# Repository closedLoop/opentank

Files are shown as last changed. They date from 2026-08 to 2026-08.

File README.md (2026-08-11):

# opentank
(WORK IN PROGRESS) A smart home sensor hub with ESP32-C6, rich analog capabilities, and full self-powering.
https://youtu.be/-s6jZ4U3TzU

## Important note!!!
The D-/D+ lines at the Type-C connector and SDA/SCL lines for U17 are still swapped!!! If you want to modify this and make changes for your own project, keep this in mind! Otherwise feel free to have a peak around in the PCB layout. Another thing: the templateforconfiguration.yaml (for Home Assistant) is still somewhat broken because the value will never go below 0 with this logic. I'll need to fix this soon. fulldevicecode.yaml is what the PCB gets programmed with, and works flawlessly as far as I've observed (2 months+ runtime so far). I also will be cleaning this up soon though by trying to make some contributions to ESPHome's repo to get rid of the need for so many lambdas. Questions? Email me at rain@haaseindustries.com or comment on my YouTube video.

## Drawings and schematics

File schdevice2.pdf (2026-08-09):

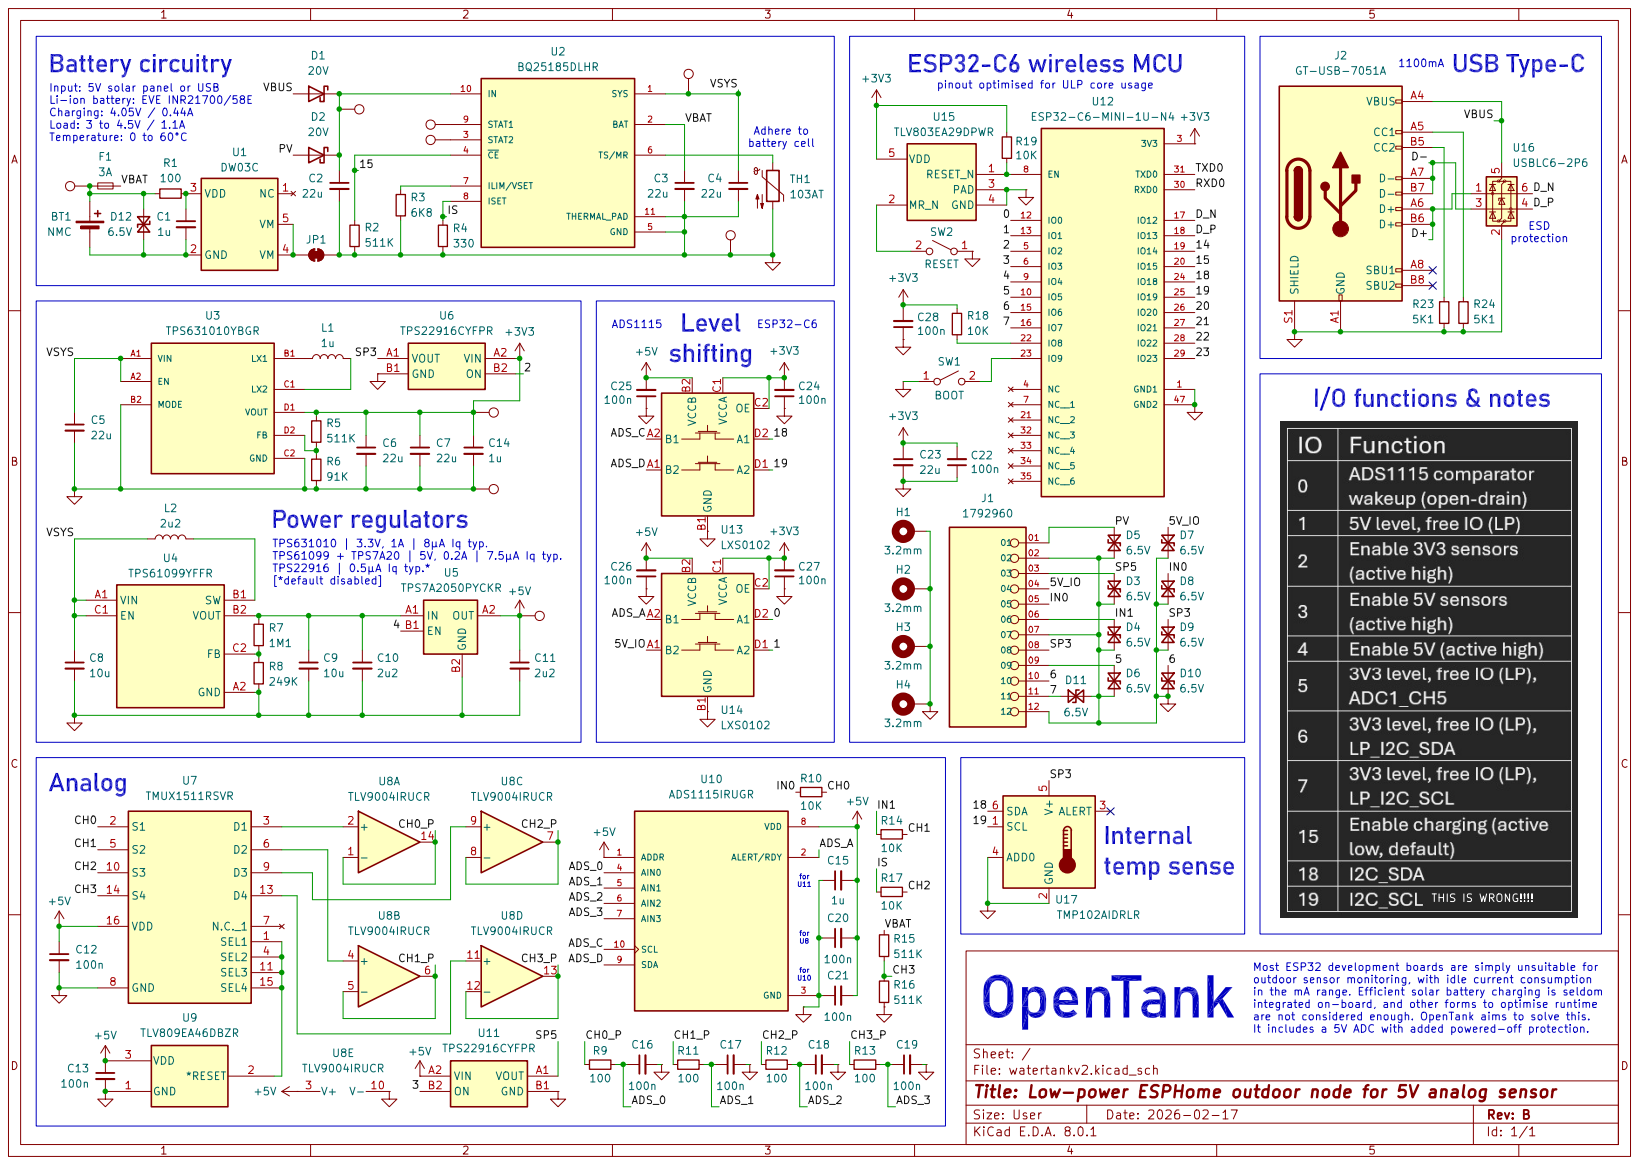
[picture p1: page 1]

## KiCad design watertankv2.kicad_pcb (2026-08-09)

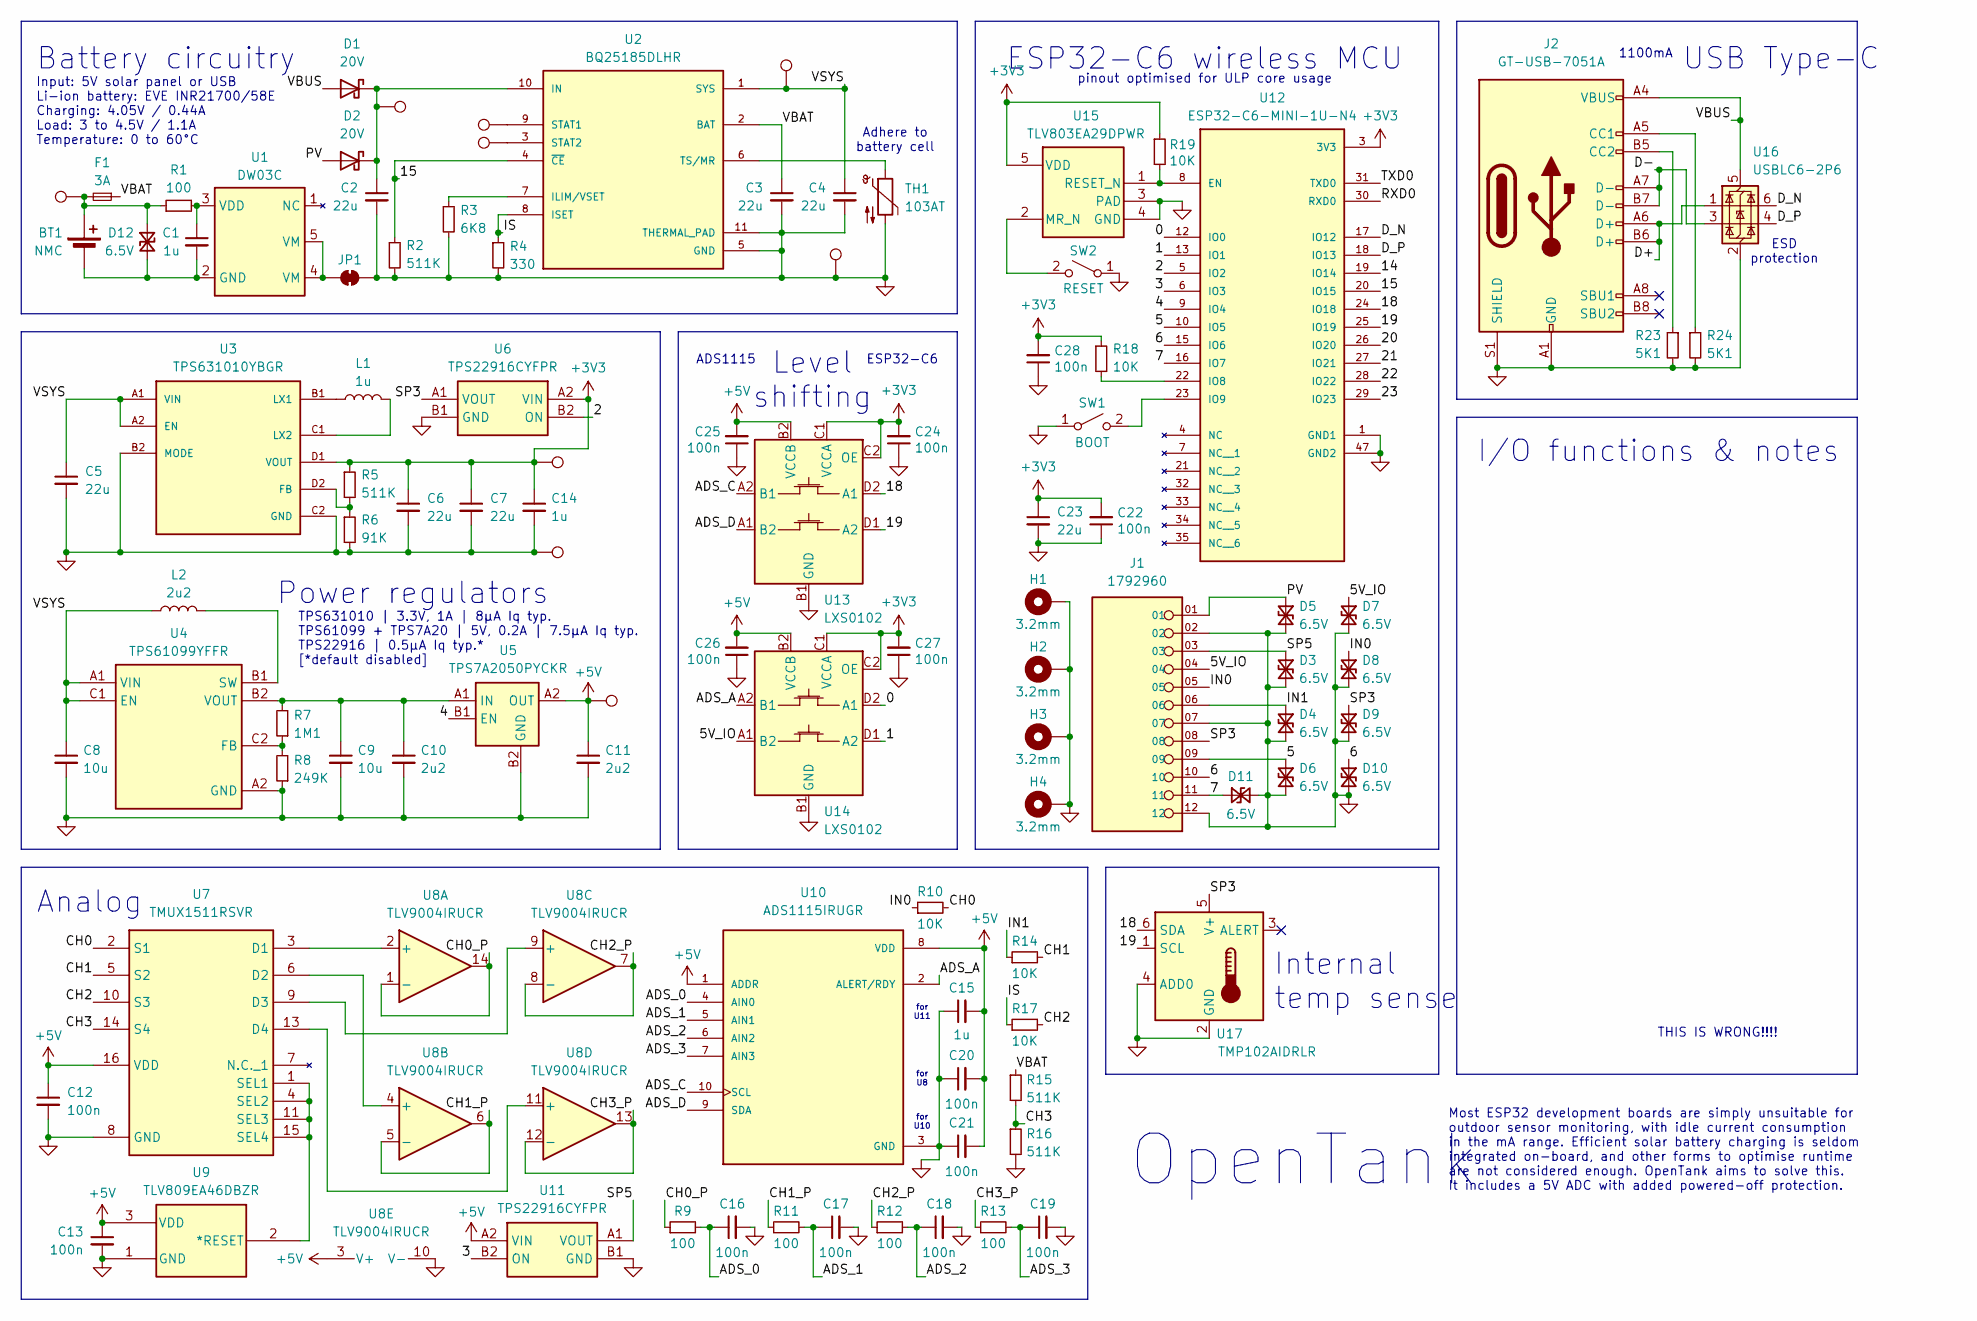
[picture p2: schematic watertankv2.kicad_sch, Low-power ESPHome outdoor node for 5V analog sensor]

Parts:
BT1: NMC; 21700holder
C1, C14, C15: 1u; C_0402_1005Metric; MPN GRM155Z71A105KE01D
C2, C3, C4, C5, C6, C7, C23: 22u; C_0805_2012Metric; MPN GRM21BR61A226ME44L
C8, C9: 10u; C_1206_3216Metric; MPN GRM31CR71C106KAC7L
C10, C11: 2u2; C_0402_1005Metric; MPN GRM155Z71A225KE44D
C12, C13, C16, C17, C18, C19, C20, C21, C22, C24, C25, C26, C27, C28: 100n; C_0201_0603Metric; MPN GRM033R61A104KE15D
D1, D2: 20V; D_SOD-123; MPN SM5817PL-TP
D3, D4, D5, D6, D7, D8, D9, D10, D11, D12: 6.5V; D_SOD-923; MPN DF2S8.2FS,L3M
F1: 3A; Fuse_1206_3216Metric; MPN C1F 3
H1, H2, H3, H4: 3.2mm; MountingHole_3.2mm_M3_DIN965_Pad
J1: 1792960; PHOENIX_1792960; MPN 1792960
J2: GT-USB-7051A; USB_C_Receptacle_G-Switch_GT-USB-7051x; MPN GT-USB-7051A
JP1: I_SNSEXT; SolderJumper-2_P1.3mm_Bridged2Bar_Pad1.0x1.5mm
L1: 1u; 74404043010A; MPN 74404043010A
L2: 2u2; L_1008_2520Metric; MPN LQM2HPN2R2MG0L
R1, R9, R11, R12, R13: 100; R_0201_0603Metric; MPN RC0201JR-07100RL
R2, R5, R15, R16: 511K; R_0201_0603Metric; MPN RC0201FR-07511KL
R3: 6K8; R_0402_1005Metric; MPN RC0402FR-076K8L
R4: 330; R_0402_1005Metric; MPN RC0402FR-07330RL
R6: 91K; R_0201_0603Metric; MPN RC0201FR-0791KL
R7: 1M1; R_0201_0603Metric; MPN RC0201FR-071M1L
R8: 249K; R_0201_0603Metric; MPN RC0201FR-07249KL
R10, R14, R17, R18, R19: 10K; R_0201_0603Metric; MPN RC0201FR-0710KL
R23, R24: 5K1; R_0402_1005Metric; MPN RC0402FR-075K1L
SW1: BOOT; SW_SPST_B3U-1000P; MPN HX-B3U-1000P-1.6N
SW2: RESET; SW_SPST_B3U-1000P; MPN HX-B3U-1000P-1.6N
TH1: 103AT; SolderWire-0.1sqmm_1x02_P3.6mm_D0.4mm_OD1mm; MPN 103AT-4-70374
TP1: BQ_IN; TestPoint_Pad_D2.0mm
TP2: STAT1; TestPoint_Pad_D2.0mm
TP3: STAT2; TestPoint_Pad_D2.0mm
TP4: 3V3; TestPoint_Pad_D2.0mm
TP5, TP9: GND; TestPoint_Pad_D2.0mm
TP6: 5V; TestPoint_Pad_D2.0mm
TP7: SYS; TestPoint_Pad_D2.0mm
TP10: VBATSNS; TestPoint_Pad_D2.0mm
U1: DW03C; SOT-23-5; MPN DW03C
U2: BQ25185DLHR; IC_BQ25185DLHR; MPN BQ25185DLHR
U3: TPS631010YBGR; IC_TPS631010YBGR; MPN TPS631010YBGR
U4: TPS61099YFFR; BGA6C40P2X3_88X123X62; MPN TPS61099YFFR
U5: TPS7A2050PYCKR; BGA4C35P2X2_62X62X33; MPN TPS7A2050PYCKR
U6, U11: TPS22916CYFPR; BGA4C40P2X2_75X75X50; MPN TPS22916CYFPR
U7: TMUX1511RSVR; QFN40P180X260X55-16N; MPN TMUX1511RSVR
U8: TLV9004IRUCR; Texas_S-PX2QFN-14; MPN TLV9004IRUCR
U9: TLV809EA46DBZR; SOT-23; MPN TLV809EA46DBZR
U10: ADS1115IRUGR; IC_ADS1115IRUGR; MPN ADS1115IRUGR
U12: ESP32-C6-MINI-1U-N4; XCVR_ESP32-C6-MINI-1U-N4; MPN ESP32-C6-MINI-1U-N4
U13, U14: LXS0102; Texas_DSBGA-8_0.9x1.9mm_Layout2x4_P0.5mm; MPN LXS0102GBAEX
U15: TLV803EA29DPWR; Texas_X2SON-5_0.8x0.8mm_P0.48mm; MPN TLV803EA29DPWR
U16: USBLC6-2P6; SOT-666; MPN USBLC6-2P6
U17: TMP102AIDRLR; SOT-563; MPN TMP102AIDRLR

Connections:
+3V3: C6.1, C7.1, C14.1, C22.2, C23.1, C24.2, C27.2, C28.2, R5.1, R18.1, R19.1, TP4.1, U3.D1 (VOUT), U6.A2 (VIN), U12.3 (3V3), U13.C1 (VCCA), U13.C2 (OE), U14.C1 (VCCA), U14.C2 (OE), U15.5 (VDD)
+5V: C11.1, C12.1, C13.1, C15.2, C20.2, C21.2, C25.2, C26.2, TP6.1, U5.A2 (OUT), U7.16 (VDD), U8.3 (V+), U9.3 (VDD), U10.1 (ADDR), U10.8 (VDD), U11.A2 (VIN), U13.B2 (VCCB), U14.B2 (VCCB)
/0: U12.12 (IO0), U14.D2 (A1)
/1: U12.13 (IO1), U14.D1 (A2)
/2: U6.B2 (ON), U12.5 (IO2)
/3: U11.B2 (ON), U12.6 (IO3)
/4: U5.B1 (EN), U12.9 (IO4)
/5: D6.1 (A1), J1.09, U12.10 (IO5)
/5V_IO: D7.1 (A1), J1.04, U14.A1 (B2)
/6: D10.1 (A1), J1.10, U12.15 (IO6)
/7: D11.1 (A1), J1.11, U12.16 (IO7)
/14: U12.19 (IO14)
/15: R2.1, U2.4 (~CE), U12.20 (IO15)
/18: U12.24 (IO18), U13.D2 (A1), U17.6 (SDA)
/19: U12.25 (IO19), U13.D1 (A2), U17.1 (SCL)
/20: U12.26 (IO20)
/21: U12.27 (IO21)
/22: U12.28 (IO22)
/23: U12.29 (IO23)
/ADS_0: C16.1, R9.2, U10.4 (AIN0)
/ADS_1: C17.1, R11.2, U10.5 (AIN1)
/ADS_2: C18.1, R12.2, U10.6 (AIN2)
/ADS_3: C19.1, R13.2, U10.7 (AIN3)
/ADS_A: U10.2 (ALERT/RDY), U14.A2 (B1)
/ADS_C: U10.10 (SCL), U13.A2 (B1)
/ADS_D: U10.9 (SDA), U13.A1 (B2)
/CH0: R10.2, U7.2 (S1)
/CH0_P: R9.1, U8.1 (-), U8.14
/CH1: R14.2, U7.5 (S2)
/CH1_P: R11.1, U8.5 (-), U8.6
/CH2: R17.2, U7.10 (S3)
/CH2_P: R12.1, U8.7, U8.8 (-)
/CH3: R15.2, R16.1, U7.14 (S4)
/CH3_P: R13.1, U8.12 (-), U8.13
/D+: J2.A6 (D+), J2.B6 (D+), U16.1 (I/O1)
/D-: J2.A7 (D-), J2.B7 (D-), U16.3 (I/O2)
/D_N: U12.17 (IO12), U16.6 (I/O1)
/D_P: U12.18 (IO13), U16.4 (I/O2)
/IN0: D8.1 (A1), J1.05, R10.1
/IN1: D4.1 (A1), J1.06, R14.1
/IS: R4.1, R17.1, U2.8 (ISET)
/PV: D2.2 (A), D5.1 (A1), J1.01
/RXD0: U12.30 (RXD0)
/SP3: D9.1 (A1), J1.08, U6.A1 (VOUT), U17.5 (V+)
/SP5: D3.1 (A1), J1.03, U11.A1 (VOUT)
/TXD0: U12.31 (TXD0)
/VBAT: C3.1, F1.1, R15.1, U2.2 (BAT)
/VBUS: D1.2 (A), J2.A4 (VBUS), J2.A9 (VBUS), J2.B4 (VBUS), J2.B9 (VBUS), U16.5 (VBUS)
/VSYS: C4.1, C5.1, C8.1, L2.1, TP7.1, U2.1 (SYS), U3.A1 (VIN), U3.A2 (EN), U4.A1 (VIN), U4.C1 (EN)
GND: C2.2, C3.2, C4.2, C5.2, C6.2, C7.2, C8.2, C9.2, C10.2, C11.2, C12.2, C13.2, C14.2, C15.1, C16.2, C17.2, C18.2, C19.2, C20.1, C21.1, C22.1, C23.2, C24.1, C25.1, C26.1, C27.1, C28.1, D3.2 (A2), D4.2 (A2), D5.2 (A2), D6.2 (A2), D7.2 (A2), D8.2 (A2), D9.2 (A2), D10.2 (A2), D11.2 (A2), H1.1, H2.1, H3.1, H4.1, J1.02, J1.07, J1.12, J2.A1 (GND), J2.A12 (GND), J2.B1 (GND), J2.B12 (GND), J2.S1 (SHIELD), JP1.1 (A), R2.2, R3.2, R4.2, R6.2, R8.1, R16.2, R23.2, R24.2, SW1.1 (A), SW2.1 (A), TH1.2, TP5.1, TP9.1, U2.5 (GND), U2.11 (THERMAL_PAD), U3.B2 (MODE), U3.C2 (GND), U4.A2 (GND), U5.B2 (GND), U6.B1 (GND), U7.8 (GND), U8.10 (V-), U9.1 (GND), U10.3 (GND), U11.B1 (GND), U12.1 (GND1), U12.2 (GND1__1), U12.11 (GND1__2), U12.14 (GND1__3), U12.36 (GND1__4), U12.37 (GND1__5), U12.38 (GND1__6), U12.39 (GND1__7), U12.40 (GND1__8), U12.41 (GND1__9), U12.42 (GND1__10), U12.43 (GND1__11), U12.44 (GND1__12), U12.45 (GND1__13), U12.46 (GND1__14), U12.47 (GND2), U12.48 (GND2__1), U12.49_1 (GND2__2), U12.49_2 (GND2__3), U12.49_3 (GND2__4), U12.49_4 (GND2__5), U12.49_5 (GND2__6), U12.49_6 (GND2__7), U12.49_7 (GND2__8), U12.49_8 (GND2__9), U12.49_9 (GND2__10), U12.50 (GND2__11), U12.51 (GND2__12), U12.52 (GND2__13), U12.53 (GND2__14), U13.B1 (GND), U14.B1 (GND), U15.3 (PAD), U15.4 (GND), U16.2 (GND), U17.2 (GND), U17.4 (ADD0)
unnamed: BT1.1 (+), D12.1 (A1), F1.2, R1.1, TP10.1
unnamed: BT1.2 (-), C1.2, D12.2 (A2), U1.2 (GND)
unnamed: C2.1, D1.1 (K), D2.1 (K), TP1.1, U2.10 (IN)
unnamed: J2.A5 (CC1), R24.1
unnamed: J2.B5 (CC2), R23.1
unnamed: JP1.2 (B), U1.4 (VM), U1.5 (VM)
unnamed: SW1.2 (B), U12.23 (IO9)
unnamed: SW2.2 (B), U15.2 (MR_N)
unnamed: C1.1, R1.2, U1.3 (VDD)
unnamed: R3.1, U2.7 (ILIM/VSET)
unnamed: TP2.1, U2.9 (STAT1)
unnamed: TP3.1, U2.3 (STAT2)
unnamed: TH1.1, U2.6 (TS/MR)
unnamed: R5.2, R6.1, U3.D2 (FB)
unnamed: L1.1, U3.B1 (LX1)
unnamed: L1.2, U3.C1 (LX2)
unnamed: R7.1, R8.2, U4.C2 (FB)
unnamed: L2.2, U4.B1 (SW)
unnamed: C9.1, C10.1, R7.2, U4.B2 (VOUT), U5.A1 (IN)
unnamed: U7.3 (D1), U8.2 (+)
unnamed: U7.6 (D2), U8.4 (+)
unnamed: U7.9 (D3), U8.9 (+)
unnamed: U7.13 (D4), U8.11 (+)
unnamed: U7.1 (SEL1), U7.4 (SEL2), U7.11 (SEL3), U7.15 (SEL4), U9.2 (*RESET)
unnamed: R19.2, U12.8 (EN), U15.1 (RESET_N)
unnamed: R18.2, U12.22 (IO8)

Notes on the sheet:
Battery circuitry
OpenTank
for U10
Internal temp sense
I/O functions & notes
for U11
THIS IS WRONG!!!!
ESD protection
1100mA
Most ESP32 development boards are simply unsuitable for outdoor sensor monitoring, with idle current consumption in the mA range. Efficient solar battery charging is seldom integrated on-board, and other forms to optimise runtime are not considered enough. OpenTank aims to solve this. It includes a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
ESP32-C6
ADS1115
Analog
Level shifting
Input: 5V solar panel or USB Li-ion battery: EVE INR21700/58E Charging: 4.05V / 0.44A Load: 3 to 4.5V / 1.1A Temperature: 0 to 60°C
for U8
pinout optimised for ULP core usage
USB Type-C
TPS631010 | 3.3V, 1A | 8μA Iq typ. TPS61099 + TPS7A20 | 5V, 0.2A | 7.5μA Iq typ. TPS22916 | 0.5μA Iq typ.* [*default disabled]
Adhere to battery cell
ESP32-C6 wireless MCU
Power regulators

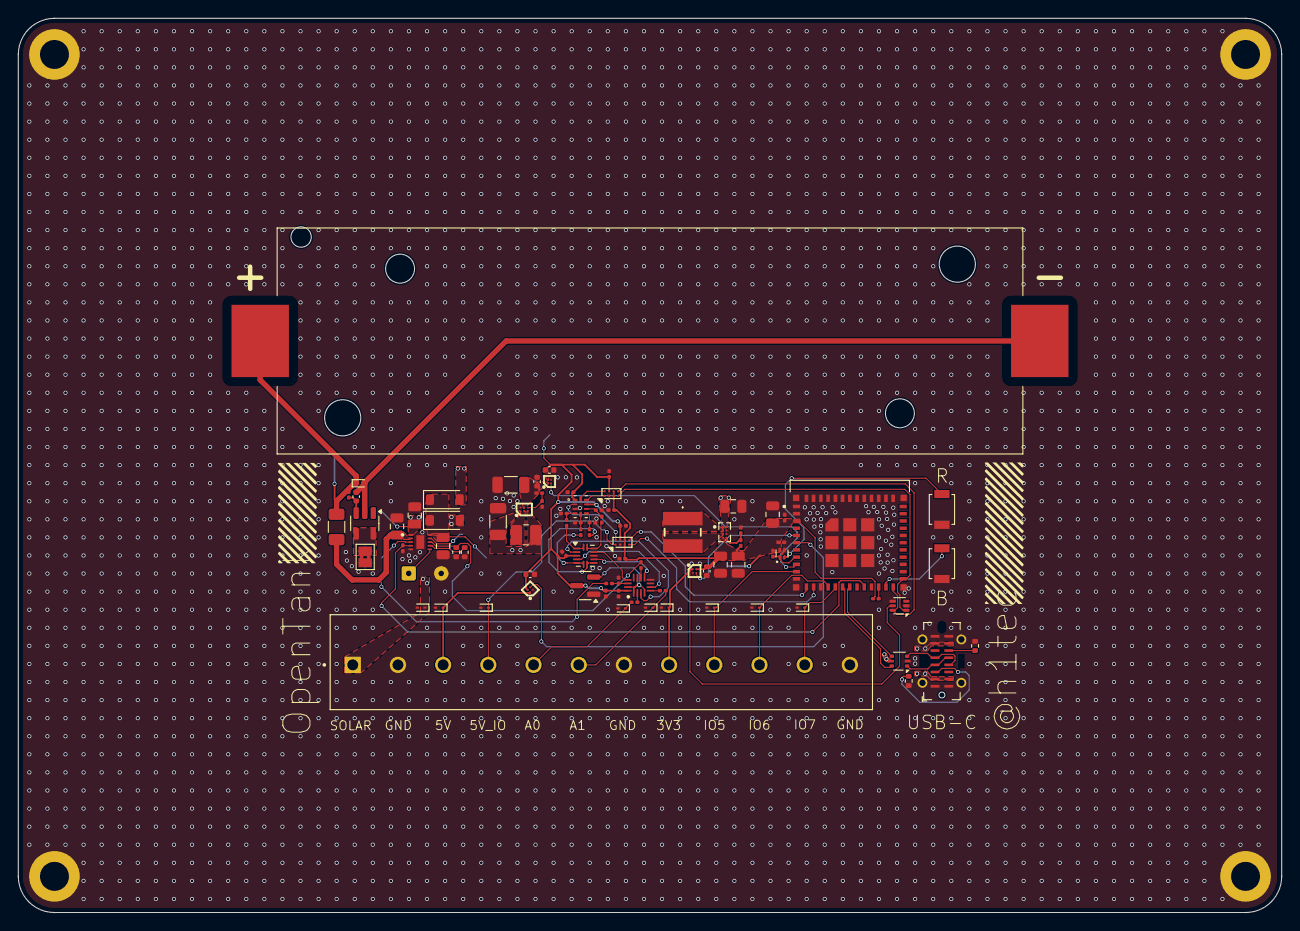
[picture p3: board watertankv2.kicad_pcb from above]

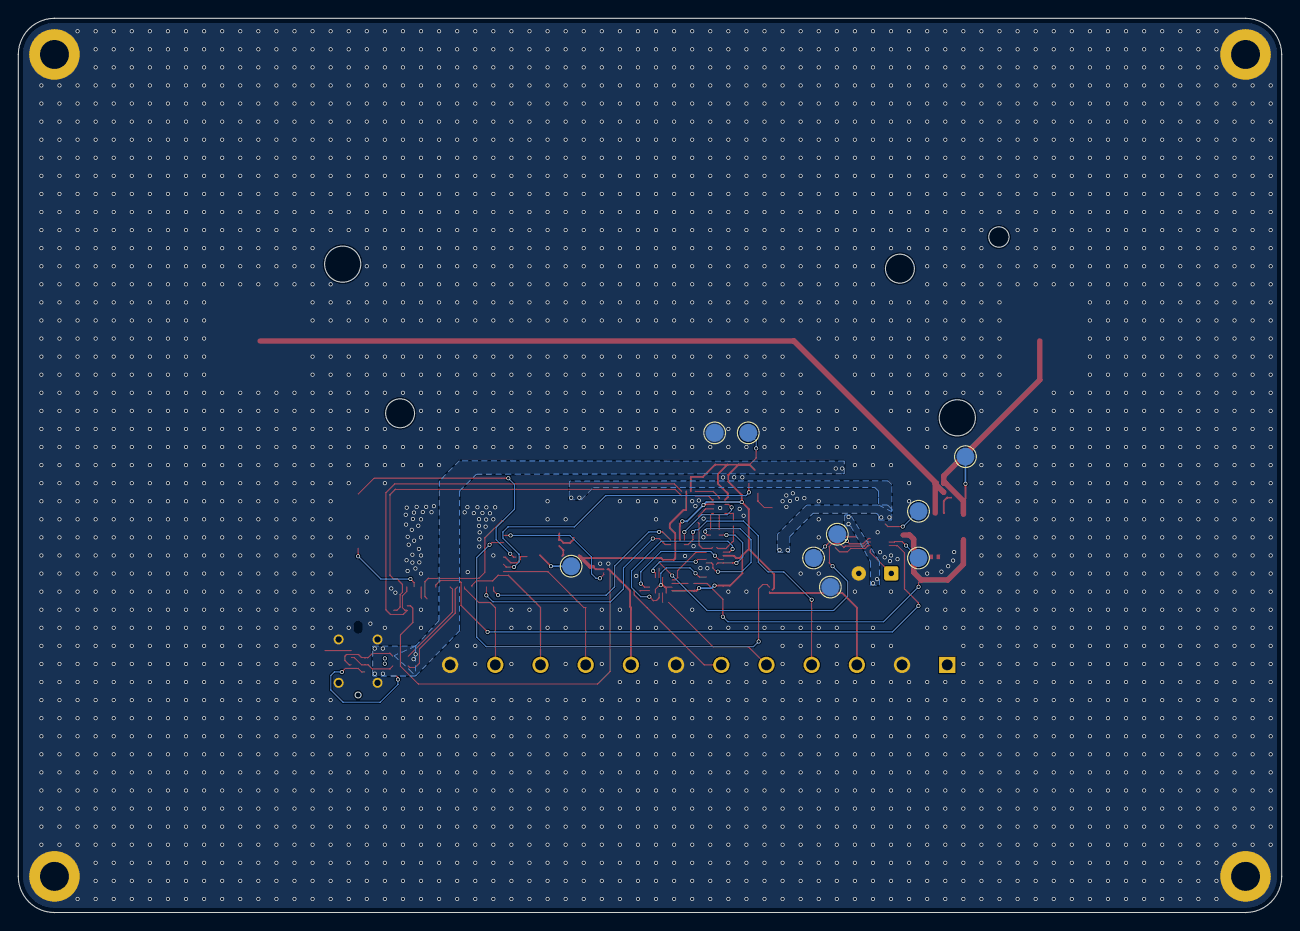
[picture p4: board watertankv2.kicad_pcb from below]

Board: 4 copper layers, 139.8 x 98.9 mm, 101 parts (9 on the bottom side), 69 nets.

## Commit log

2026-08-09 Add schematic
2026-08-09 Update LICENSE
    Updating LICENSE since uploading full KiCad files
2026-08-09 PCB files
    [watertankv2.kicad_pcb, watertankv2.kicad_sch]
